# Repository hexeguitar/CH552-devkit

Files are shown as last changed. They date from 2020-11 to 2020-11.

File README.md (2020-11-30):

# CH552 devkit

### CH552 development board with hardware reboot into bootloader feature.  

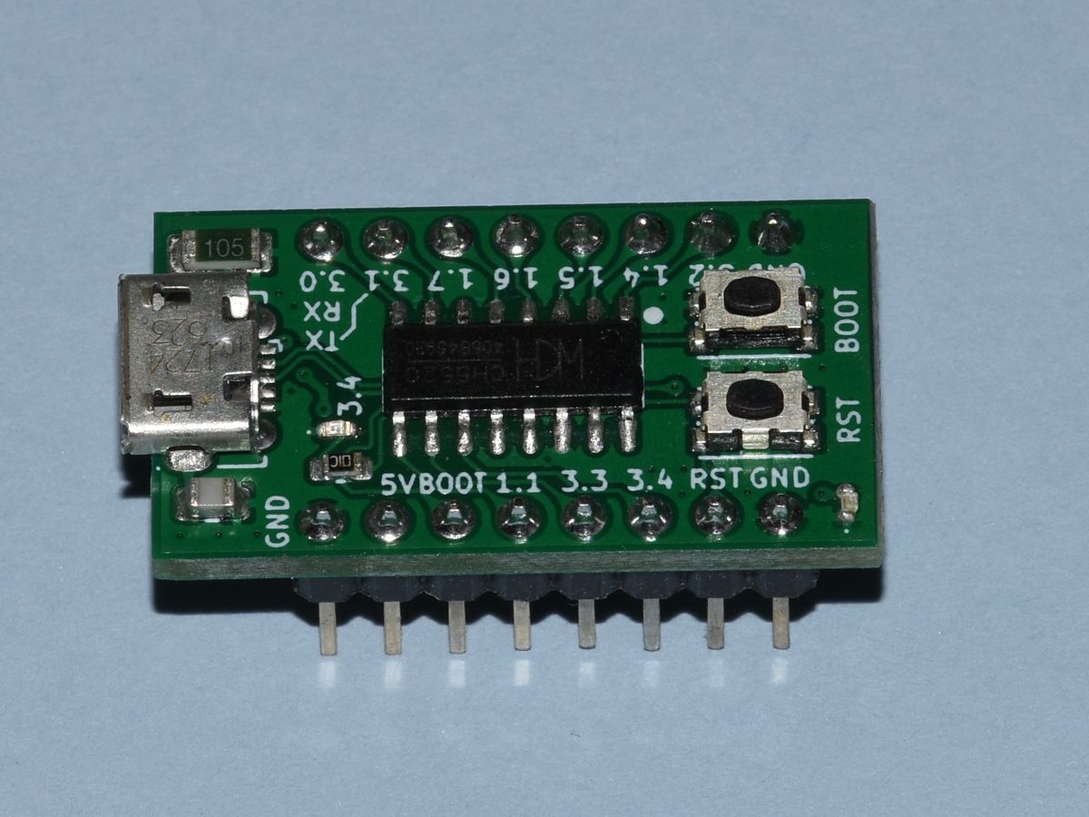
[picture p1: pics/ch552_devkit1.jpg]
  
 
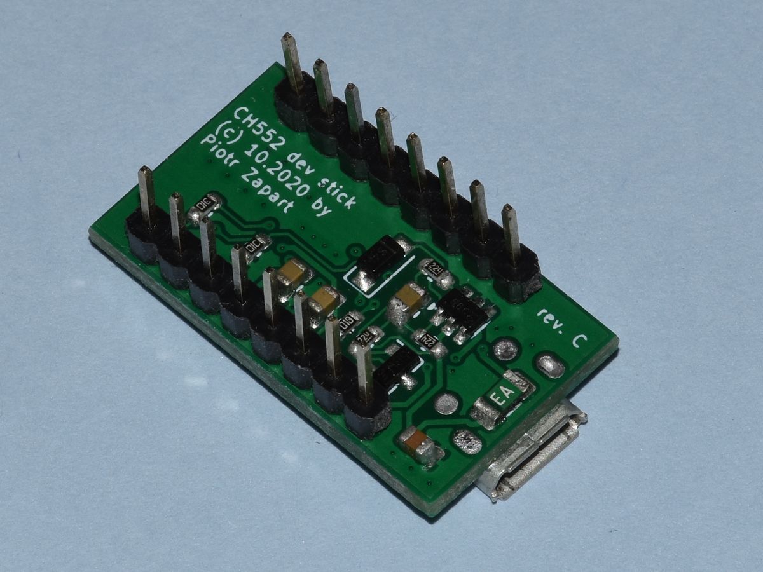
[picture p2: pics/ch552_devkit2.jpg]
  

### Reboot circuit  

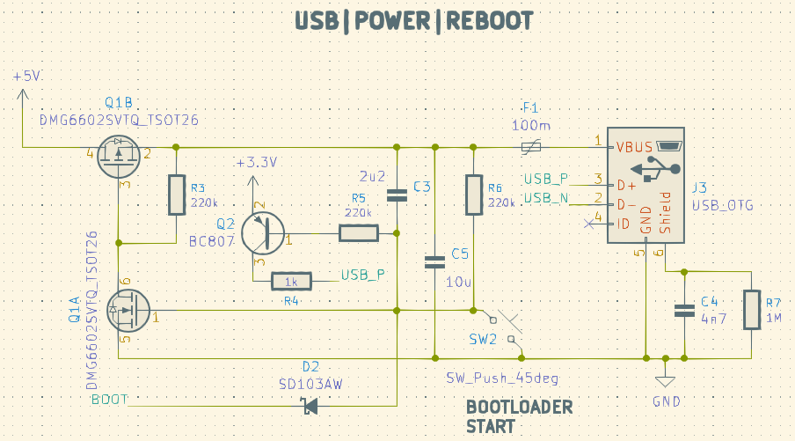
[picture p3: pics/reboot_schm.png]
  

Pressing and releasing the BOOTLOADER button will cycle the power and start the MCU with 1k pull-up on the USB-P line. This will start the built in USB/Serial bootoader. External BOOT input is provided for triggering via DTR or other active low signal.  

Take a look here for similar circuit for the CH559 series:  
https://github.com/hexeguitar/CH55x-HW-reboot  

Python programming script for both USB and serial port can be found here:  
https://github.com/hexeguitar/CH55x_python_flasher  
___
(c) 11.2020 by Piotr Zapart  
www.hexefx.com

[pic1]: pics/ch552_devkit1.jpg "CH552 devkit"
[pic2]: pics/ch552_devkit2.jpg "CH552 devkit"

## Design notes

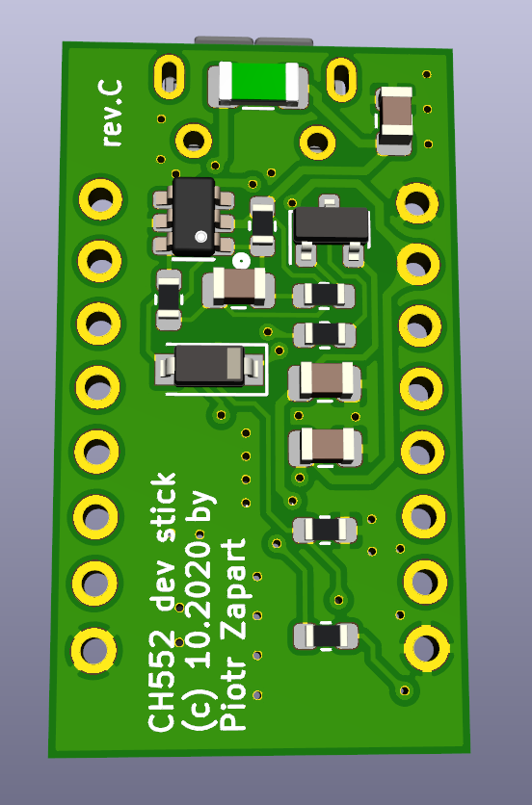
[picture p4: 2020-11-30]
pics/pcb_rnd_btm.png

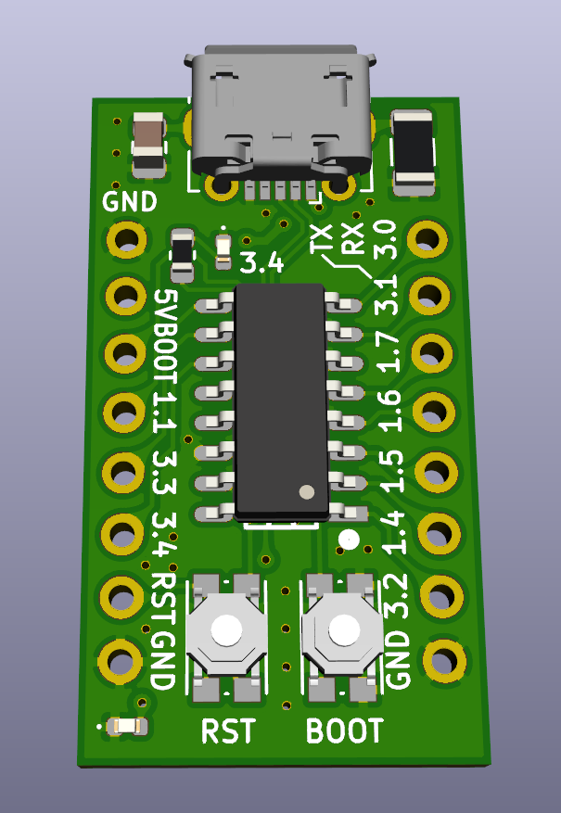
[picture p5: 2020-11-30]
pics/pcb_rnd_top.png

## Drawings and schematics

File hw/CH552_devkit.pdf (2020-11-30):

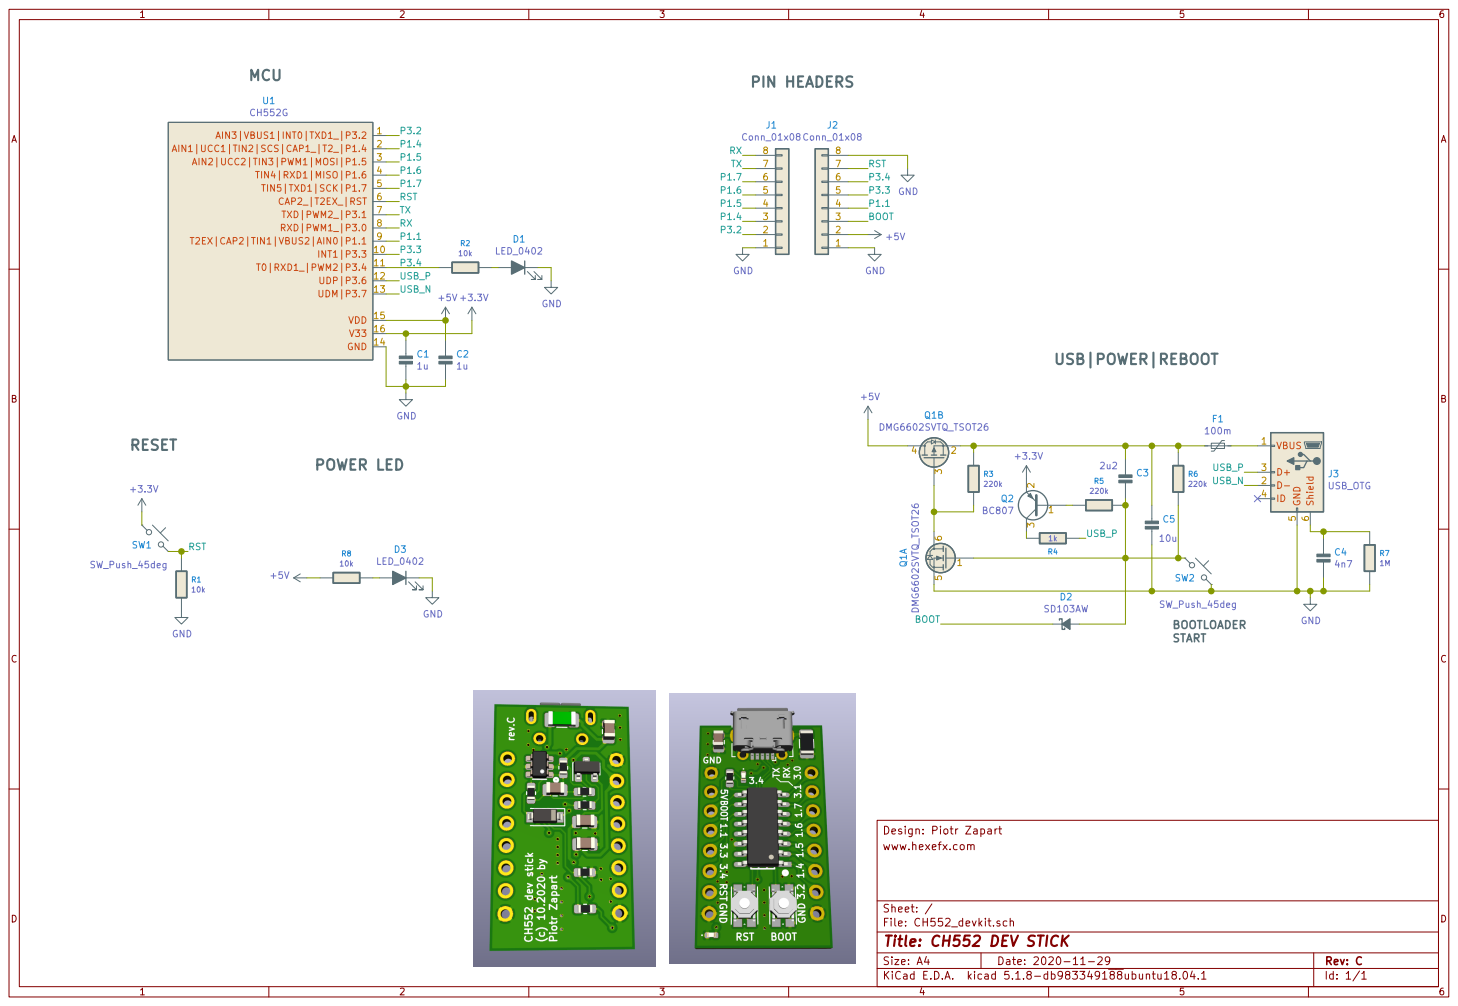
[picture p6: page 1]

File: CH552_devkit.sch Sheet: / www.hexefx.com

Id: 1/1 Title: CH552 DEV STICK

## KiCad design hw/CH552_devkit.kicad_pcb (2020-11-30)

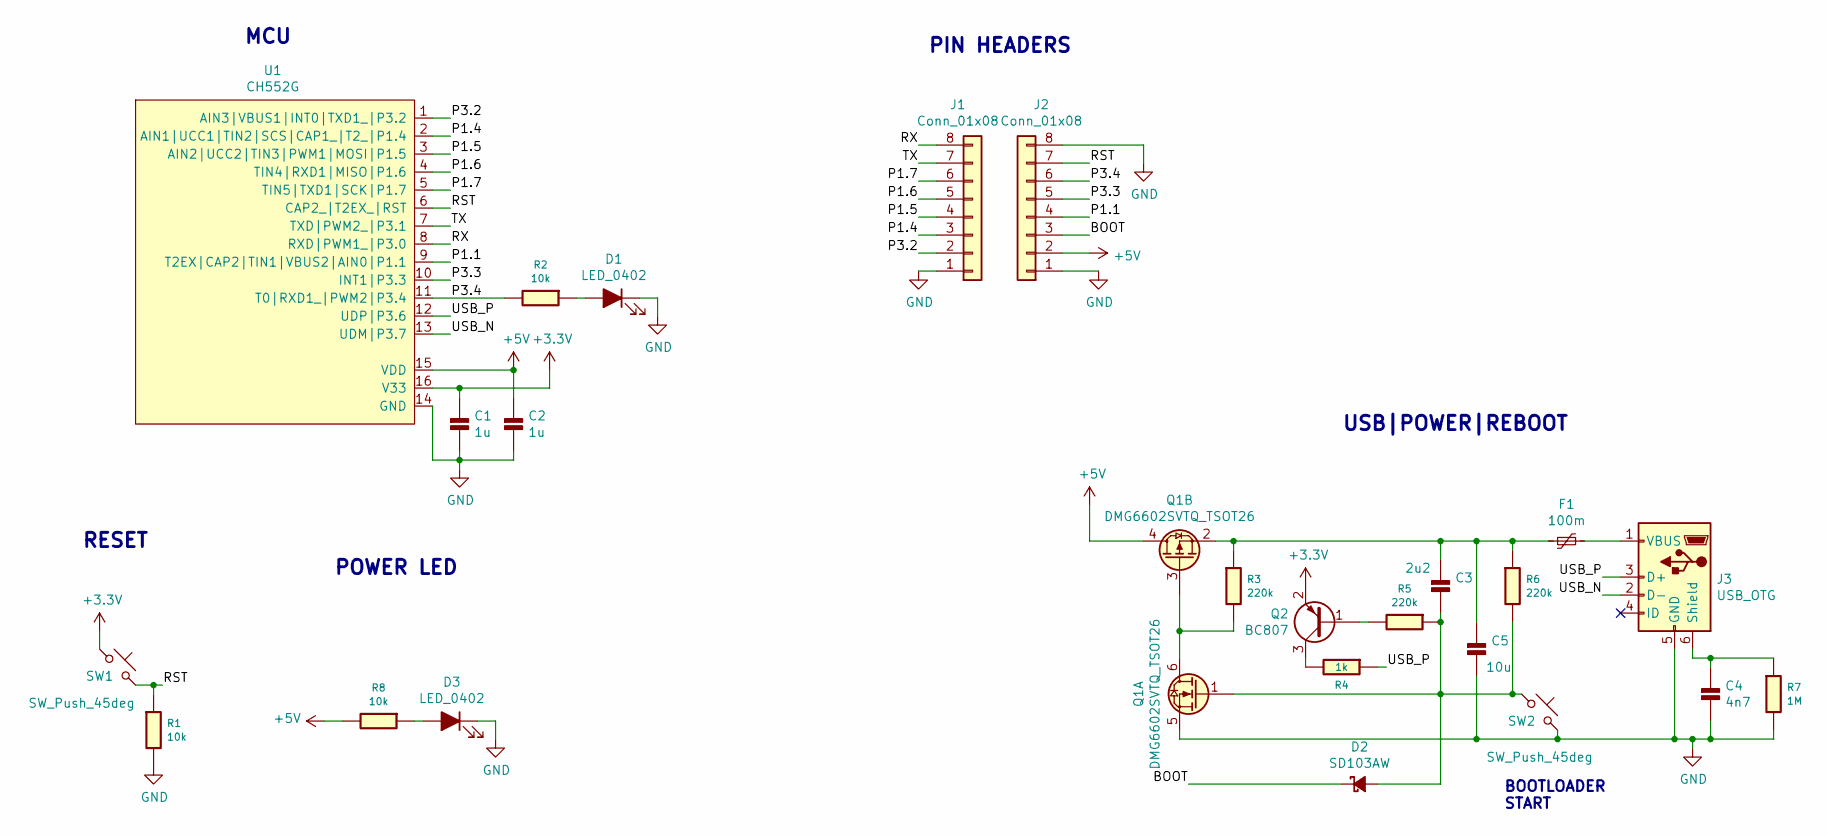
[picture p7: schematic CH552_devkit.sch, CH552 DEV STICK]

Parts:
C1, C2: 1u; Hx_C_0805_2012Metric
C3: 2u2; Hx_C_0805_2012Metric
C4: 4n7; Hx_C_0805_2012Metric
C5: 10u; Hx_C_0805_2012Metric
D1, D3: LED_0402; LED_0402_1005Metric
D2: SD103AW; D_SOD-123
F1: 100m; Fuse_1206_3216Metric
J1, J2: Conn_01x08; PinHeader_1x08_P2.54mm_Vertical
J3: USB_OTG; USB_Micro-B_Molex-105017-0001
Q1: DMG6602SVTQ_TSOT26; TSOT26
Q2: BC807; SOT-23
R1, R2, R8: 10k; Hx_R_0603_1608Metric
R3, R5, R6: 220k; Hx_R_0603_1608Metric
R4: 1k; Hx_R_0603_1608Metric
R7: 1M; Hx_R_1206_3216Metric
SW1, SW2: SW_Push_45deg; SW_Push_1P1T_NO_CK_KMR2
U1: CH552G; SOIC16

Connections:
+3V3: C1.1, Q2.2 (E), SW1.1, U1.16 (V33)
+5V: C2.1, J2.2, Q1.4 (D), R8.2, U1.15 (VDD)
/BOOT: D2.1 (K), J2.3
/P1.1: J2.4, U1.9 (T2EX|CAP2|TIN1|VBUS2|AIN0|P1.1)
/P1.4: J1.3, U1.2 (AIN1|UCC1|TIN2|SCS|CAP1_|T2_|P1.4)
/P1.5: J1.4, U1.3 (AIN2|UCC2|TIN3|PWM1|MOSI|P1.5)
/P1.6: J1.5, U1.4 (TIN4|RXD1|MISO|P1.6)
/P1.7: J1.6, U1.5 (TIN5|TXD1|SCK|P1.7)
/P3.2: J1.2, U1.1 (AIN3|VBUS1|INT0|TXD1_|P3.2)
/P3.3: J2.5, U1.10 (INT1|P3.3)
/P3.4: J2.6, R2.2, U1.11 (T0|RXD1_|PWM2|P3.4)
/RST: J2.7, R1.1, SW1.2, U1.6 (CAP2_|T2EX_|RST)
/RX: J1.8, U1.8 (RXD|PWM1_|P3.0)
/TX: J1.7, U1.7 (TXD|PWM2_|P3.1)
/USB_N: J3.2 (D-), U1.13 (UDM|P3.7)
/USB_P: J3.3 (D+), R4.1, U1.12 (UDP|P3.6)
GND: C1.2, C2.2, C4.2, C5.2, D1.1 (K), D3.1 (K), J1.1, J2.1, J2.8, J3.5 (GND), Q1.5 (S), R1.2, R7.2, SW2.2, U1.14 (GND)
unnamed: C3.1, C5.1, F1.2, Q1.2 (S), R3.1, R6.1
unnamed: C3.2, D2.2 (A), Q1.1 (G), R5.1, R6.2, SW2.1
unnamed: C4.1, J3.6 (Shield), R7.1
unnamed: D1.2 (A), R2.1
unnamed: D3.2 (A), R8.1
unnamed: F1.1, J3.1 (VBUS)
unnamed: Q1.3 (G), Q1.6 (D), R3.2
unnamed: Q2.1 (B), R5.2
unnamed: Q2.3 (C), R4.2

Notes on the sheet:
USB|POWER|REBOOT
PIN HEADERS
MCU
RESET
POWER LED
BOOTLOADER START

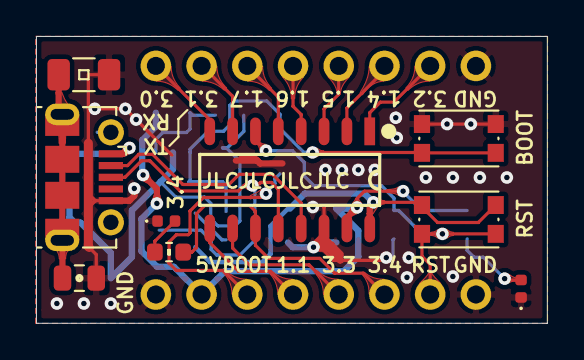
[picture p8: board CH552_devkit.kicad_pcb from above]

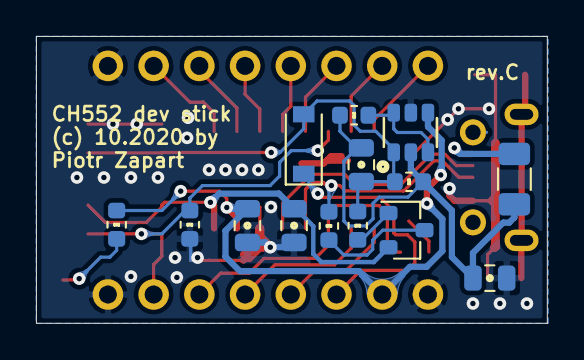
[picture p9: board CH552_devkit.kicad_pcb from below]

Board: 2 copper layers, 28.4 x 15.9 mm, 25 parts (14 on the bottom side), 26 nets.
